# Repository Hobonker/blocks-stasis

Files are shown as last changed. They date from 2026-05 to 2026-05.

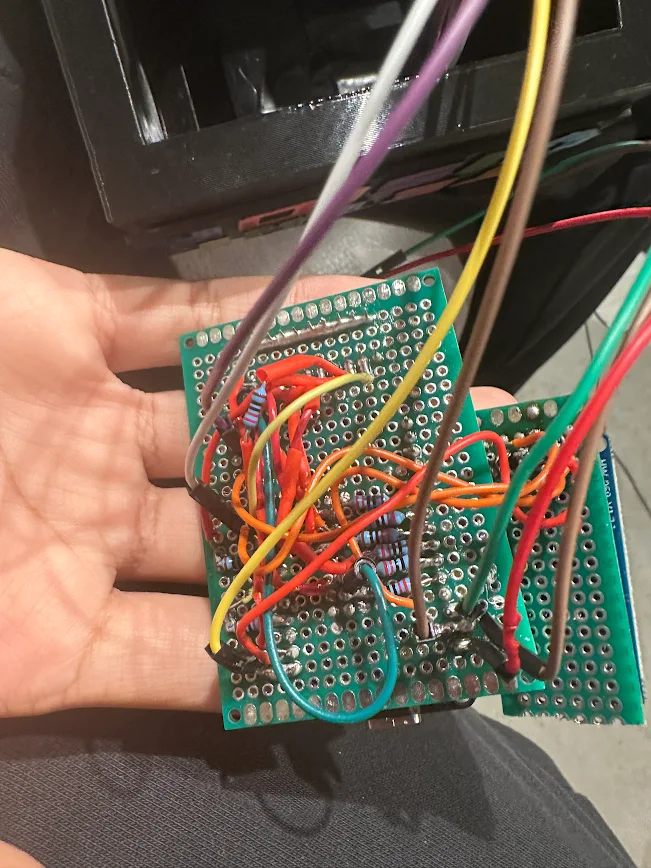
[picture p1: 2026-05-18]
Wiring/Main Perf.webp

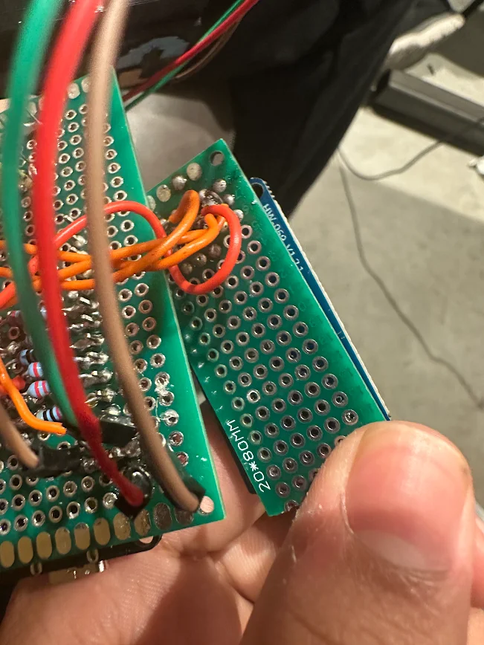
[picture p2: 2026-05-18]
Wiring/OLED.webp

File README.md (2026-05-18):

# TETRIVISION - Gesture Controlled Tetris




Play Tetris with your hands and your voice. A webcam tracks the center of your hand for movement to move and drop pieces, yell into the microphone to rotate pieces clockwise the louder you scream, the more the piece spins. The game itself runs on an ESP32-WROOM driving a 8x32 NeoPixel LED matrix, with a 7-segment display for score, an OLED showing the next piece shape, and a LED bar for mic input volume.

# Demo

https://www.youtube.com/watch?v=66Lr5TsQWm4

# How To Play

- Always keep hand open palm facing the screen
- Place hand at center of the screen (neutral zone)
- Swipe your hand to the left or right to move the falling piece
- Swipe your hand down to hard drop
- Yell to rotate the falling piece clockwise
- Try to clear as many lines as you can by creating rows of 8

# BOM

| Part Name | Count |
|---|---|
| ESP32-S3 | 1 |
| WS2812B NeoPixel Matrix (8x32) | 1 |
| TM1637 4-digit 7-segment display | 1 |
| SSD1306 OLED 0.96" | 1 |
| USB cable (ESP32 to computer) | 1 |
| Webcam (built-in or external) | 1 |
| Microphone (built-in or external) | 1 |
| Computer with USB-C | 1 |
| Perf Board | 1 |
| Jumper Cables | 20 |
| 3D Printed Case | 1 |
| Computer | 1 |
| LED Lights | 1 |

# Wiring Diagram

| From | From Label | To | To Label |
| :--- | :--- | :--- | :--- |
| ESP32 | VIN (5V) | WS2812B Matrix | VCC |
| ESP32 | GND | WS2812B Matrix | GND |
| ESP32 | GPIO13 |  WS2812B Matrix | DIN |
| ESP32 | 3V3 | SSD1306 OLED | VCC |
| ESP32 | GND | SSD1306 OLED | GND |
| ESP32 | GPIO18 | SSD1306 OLED | SCK |
| ESP32 | GPIO23 | SSD1306 OLED | SDA |
| ESP32 | 3V3 | TM1637 7-seg | VCC |
| ESP32 | GND | TM1637 7-seg | GND |
| ESP32 | GPIO22 | TM1637 7-seg | CLK |
| ESP32 | GPIO21 | TM1637 7-seg | DIO |
| ESP32 | GPIO14 | Resistor LED1 | IN |
| Resistor LED1 | OUT | Volume Bar LED1 | DIN |
| ESP32 | GPIO27 | Resistor LED2 | IN |
| Resistor LED2 | OUT | Volume Bar LED2 | DIN |
| ESP32 | GPIO26 | Resistor LED3 | IN |
| Resistor LED3 | OUT | Volume Bar LED3 | DIN |
| ESP32 | GPIO25 | Resistor LED4 | IN |
| Resistor LED4 | OUT | Volume Bar LED4 | DIN |
| ESP32 | GPIO33 | Resistor LED5 | IN |
| Resistor LED5 | OUT | Volume Bar LED5 | DIN |
| ESP32 | GPIO32 | Resistor LED6 | IN |
| Resistor LED6 | OUT | Volume Bar LED6 | DIN |
| ESP32 | GPIO5 | Resistor LED7 | IN |
| Resistor LED7 | OUT | Volume Bar LED7 | DIN |
| ESP32 | GPIO19 | Resistor LED8 | IN |
| Resistor LED8 | OUT | Volume Bar LED8 | DIN |
| ESP32 | GPIO2 | Resistor LED9 | IN |
| Resistor LED9 | OUT | Volume Bar LED9 | DIN |

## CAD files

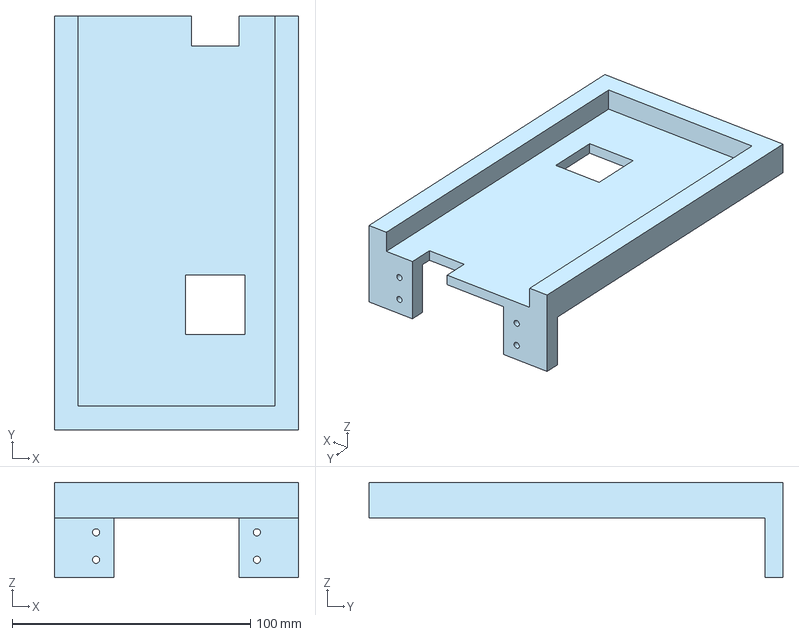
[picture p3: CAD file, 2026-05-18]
CAD/Matrix Display Bottom.step
102.5 x 173.8 x 40.0 mm

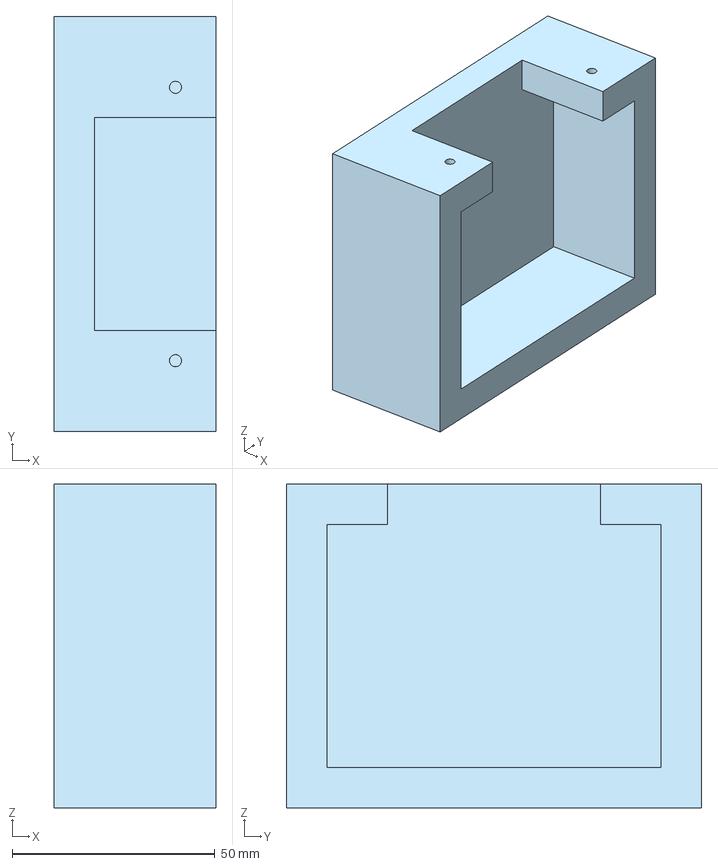
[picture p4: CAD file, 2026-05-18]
CAD/backtop.step
40.0 x 102.5 x 80.0 mm

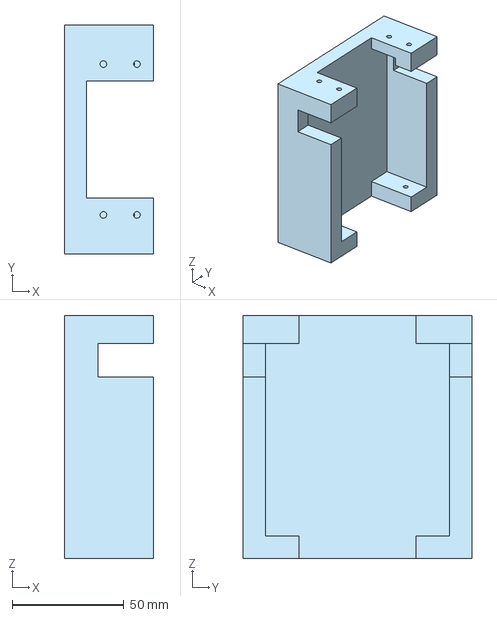
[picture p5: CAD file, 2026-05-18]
CAD/middleback.step
40.0 x 102.5 x 108.8 mm

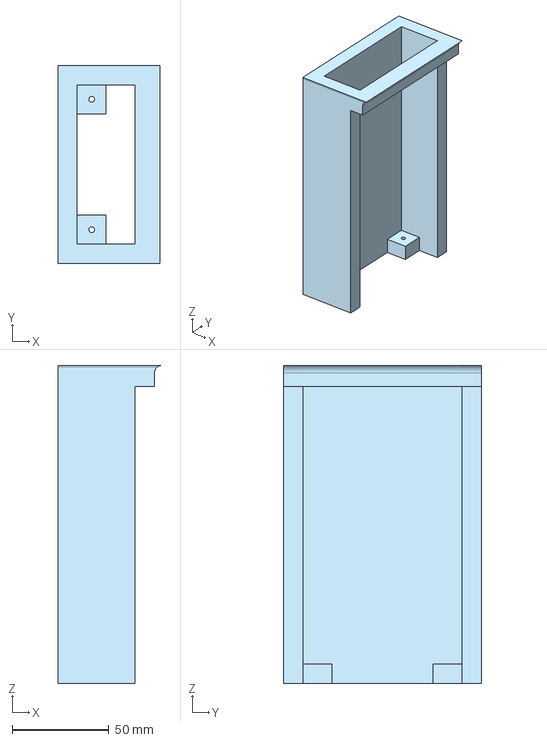
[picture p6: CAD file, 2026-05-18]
CAD/backbottom.step
52.9 x 102.5 x 164.6 mm

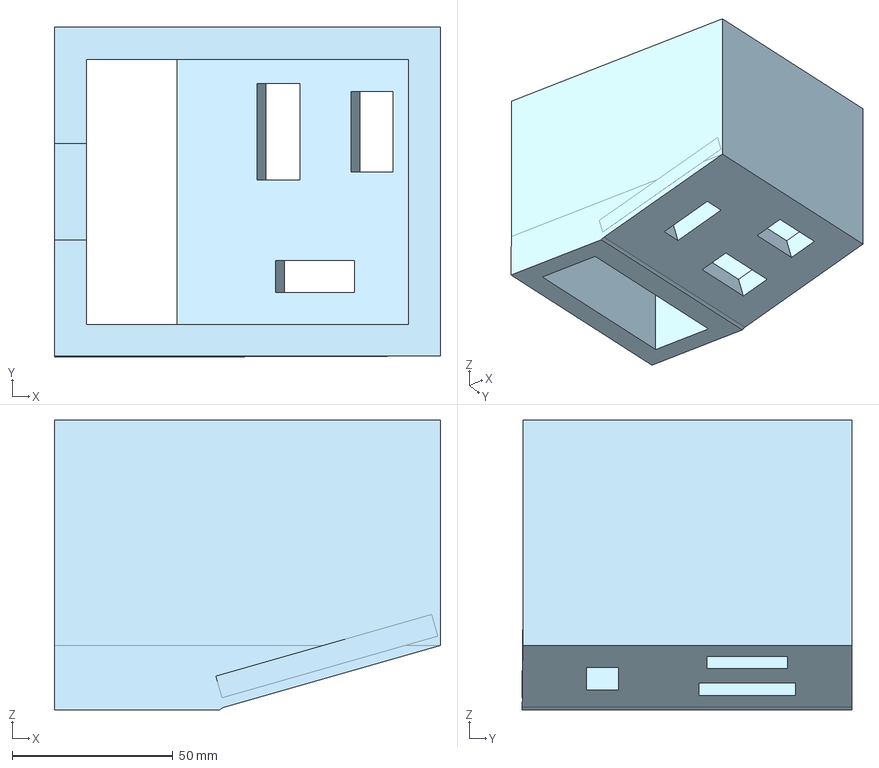
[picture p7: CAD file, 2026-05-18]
CAD/Base Case.step
120.0 x 102.5 x 90.0 mm

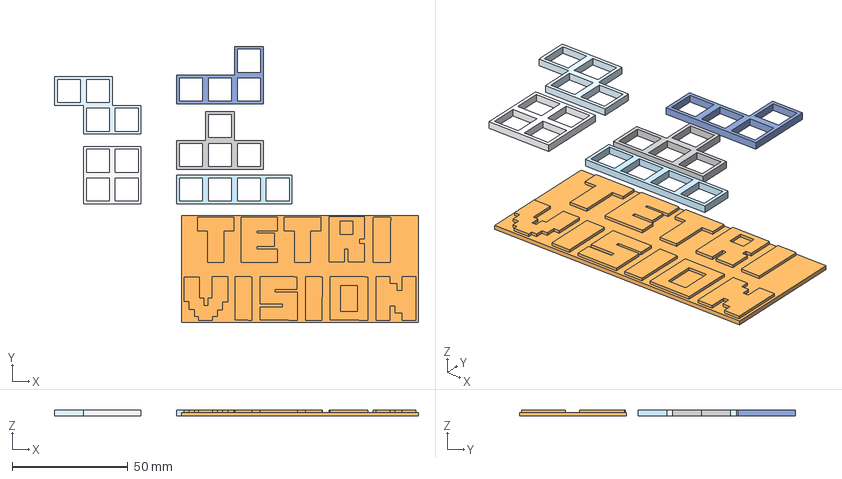
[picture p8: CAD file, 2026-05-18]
CAD/Stencils & Logo.step
157.5 x 119.6 x 2.50 mm

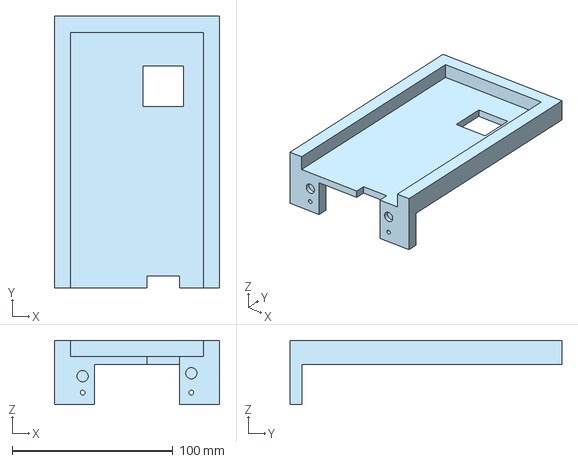
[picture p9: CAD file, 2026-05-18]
CAD/Matrix Display Top.step
102.5 x 168.8 x 40.0 mm

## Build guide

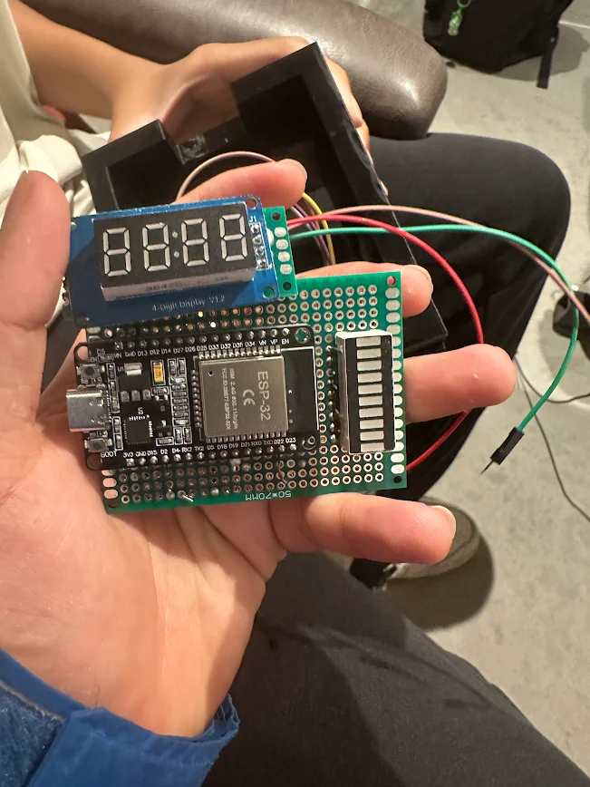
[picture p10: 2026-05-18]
Wiring/Perf Front.webp

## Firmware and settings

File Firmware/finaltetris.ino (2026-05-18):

#include <Adafruit_NeoPixel.h>
#include <TM1637Display.h>
#include <Wire.h>
#include <Adafruit_GFX.h>
#include <Adafruit_SSD1306.h>

// --- NeoPixel ---
#define PIN 13
#define W 8
#define H 32
#define NUM_LEDS (W * H)
Adafruit_NeoPixel strip(NUM_LEDS, PIN, NEO_GRB + NEO_KHZ800);

// --- TM1637 7-seg (score) ---
#define TM_CLK 22
#define TM_DIO 21
TM1637Display display(TM_CLK, TM_DIO);

// --- SSD1306 OLED (next piece) ---
#define OLED_SDA 23
#define OLED_SCL 18
#define SCREEN_WIDTH 128
#define SCREEN_HEIGHT 64
Adafruit_SSD1306 oled(SCREEN_WIDTH, SCREEN_HEIGHT, &Wire, -1);

// --- Volume LED bar ---
const int LED_PINS[]   = {14, 27, 26, 25, 33, 32, 5, 19, 2, 4};
const int NUM_VOL_LEDS = 10;
int currentLevel  = 0;
int targetLevel   = 0;
unsigned long lastDecay = 0;
const int DECAY_INTERVAL = 60;

// --- Start gate ---
bool gameStarted = false;

// --- Game state ---
uint32_t board[H][W];
int curPiece, curRot, curRow, curCol;
uint32_t COLORS[7];
int score = 0;
int incomingPiece = 0;
unsigned long lastFall = 0;
#define FALL_SPEED 600
String serialBuf = "";

const int8_t PIECES[7][4][4][2] = {
  // I
  {{{0,0},{0,1},{0,2},{0,3}},{{0,0},{1,0},{2,0},{3,0}},{{0,0},{0,1},{0,2},{0,3}},{{0,0},{1,0},{2,0},{3,0}}},
  // O
  {{{0,0},{0,1},{1,0},{1,1}},{{0,0},{0,1},{1,0},{1,1}},{{0,0},{0,1},{1,0},{1,1}},{{0,0},{0,1},{1,0},{1,1}}},
  // T
  {{{0,1},{1,0},{1,1},{1,2}},{{0,0},{1,0},{1,1},{2,0}},{{0,0},{0,1},{0,2},{1,1}},{{0,1},{1,0},{1,1},{2,1}}},
  // S
  {{{0,1},{0,2},{1,0},{1,1}},{{0,0},{1,0},{1,1},{2,1}},{{0,1},{0,2},{1,0},{1,1}},{{0,0},{1,0},{1,1},{2,1}}},
  // Z
  {{{0,0},{0,1},{1,1},{1,2}},{{0,1},{1,0},{1,1},{2,0}},{{0,0},{0,1},{1,1},{1,2}},{{0,1},{1,0},{1,1},{2,0}}},
  // J
  {{{0,0},{1,0},{1,1},{1,2}},{{0,0},{0,1},{1,0},{2,0}},{{0,0},{0,1},{0,2},{1,2}},{{0,1},{1,1},{2,0},{2,1}}},
  // L
  {{{0,2},{1,0},{1,1},{1,2}},{{0,0},{1,0},{2,0},{2,1}},{{0,0},{0,1},{0,2},{1,0}},{{0,0},{0,1},{1,1},{2,1}}}
};

const bool PIECE_PREVIEW[7][4][4] = {
  {{0,0,0,0},{1,1,1,1},{0,0,0,0},{0,0,0,0}},  // I
  {{0,1,1,0},{0,1,1,0},{0,0,0,0},{0,0,0,0}},  // O
  {{0,1,0,0},{1,1,1,0},{0,0,0,0},{0,0,0,0}},  // T
  {{0,1,1,0},{1,1,0,0},{0,0,0,0},{0,0,0,0}},  // S
  {{1,1,0,0},{0,1,1,0},{0,0,0,0},{0,0,0,0}},  // Z
  {{1,0,0,0},{1,1,1,0},{0,0,0,0},{0,0,0,0}},  // J
  {{0,0,1,0},{1,1,1,0},{0,0,0,0},{0,0,0,0}}   // L
};

const char* PIECE_NAMES[7] = {"I","O","T","S","Z","J","L"};

// ─── Helpers ─────────────────────────────────────────────

void updateVolumeLEDs() {
  if (millis() - lastDecay > DECAY_INTERVAL) {
    if (currentLevel > 0) currentLevel--;
    lastDecay = millis();
  }
  for (int i = 0; i < NUM_VOL_LEDS; i++)
    digitalWrite(LED_PINS[i], i < currentLevel ? HIGH : LOW);
}

void drawNextPiece(int piece) {
  oled.clearDisplay();
  oled.setTextSize(1);
  oled.setTextColor(SSD1306_WHITE);
  oled.setCursor(0, 0);
  oled.print("NEXT:");
  oled.print(PIECE_NAMES[piece]);

  int cellSize = 14, gap = 2;
  int gridW = 4 * (cellSize + gap);
  int gridH = 4 * (cellSize + gap);
  int startX = (SCREEN_WIDTH - gridW) / 2;
  int startY = (SCREEN_HEIGHT - gridH) / 2 + 8;

  for (int r = 0; r < 4; r++)
    for (int c = 0; c < 4; c++)
      if (PIECE_PREVIEW[piece][r][c])
        oled.fillRect(startX + c*(cellSize+gap), startY + r*(cellSize+gap), cellSize, cellSize, SSD1306_WHITE);
  oled.display();
}

int xyToLED(int row, int col) {
  int flippedRow = (H - 1) - row;
  if (flippedRow % 2 == 0) return flippedRow * W + col;
  else return flippedRow * W + (W - 1 - col);
}

bool collides(int piece, int rot, int row, int col) {
  for (int i = 0; i < 4; i++) {
    int r = row + PIECES[piece][rot][i][0];
    int c = col + PIECES[piece][rot][i][1];
    if (r < 0 || r >= H || c < 0 || c >= W) return true;
    if (board[r][c]) return true;
  }
  return false;
}

void lockPiece() {
  for (int i = 0; i < 4; i++) {
    int r = curRow + PIECES[curPiece][curRot][i][0];
    int c = curCol + PIECES[curPiece][curRot][i][1];
    if (r >= 0 && r < H && c >= 0 && c < W)
      board[r][c] = COLORS[curPiece];
  }
  score += 10;
  display.showNumberDec(score, false);
  Serial.print("Score: "); Serial.println(score);
}

void clearLines() {
  for (int r = H - 1; r >= 0; r--) {
    bool full = true;
    for (int c = 0; c < W; c++)
      if (!board[r][c]) { full = false; break; }
    if (full) {
      for (int rr = r; rr > 0; rr--)
        for (int c = 0; c < W; c++)
          board[rr][c] = board[rr-1][c];
      for (int c = 0; c < W; c++)
        board[0][c] = 0;
      r++;
      score += 50;
      display.showNumberDec(score, false);
      Serial.print("Score: "); Serial.println(score);
    }
  }
}

void render() {
  for (int r = 0; r < H; r++)
    for (int c = 0; c < W; c++)
      strip.setPixelColor(xyToLED(r, c), board[r][c]);
  for (int i = 0; i < 4; i++) {
    int r = curRow + PIECES[curPiece][curRot][i][0];
    int c = curCol + PIECES[curPiece][curRot][i][1];
    if (r >= 0 && r < H && c >= 0 && c < W)
      strip.setPixelColor(xyToLED(r, c), COLORS[curPiece]);
  }
  strip.show();
}

void showIdleScreen() {
  // Blue border on NeoPixel matrix, everything else black
  strip.clear();
  for (int c = 0; c < W; c++) {
    strip.setPixelColor(xyToLED(0, c),   strip.Color(0, 0, 60));
    strip.setPixelColor(xyToLED(H-1, c), strip.Color(0, 0, 60));
  }
  for (int r = 1; r < H-1; r++) {
    strip.setPixelColor(xyToLED(r, 0),   strip.Color(0, 0, 60));
    strip.setPixelColor(xyToLED(r, W-1), strip.Color(0, 0, 60));
  }
  strip.show();

  // OLED waiting message
  oled.clearDisplay();
  oled.setTextSize(1);
  oled.setTextColor(SSD1306_WHITE);
  oled.setCursor(0, 20);
  oled.print("  TETRIS");
  oled.setCursor(0, 36);
  oled.print("Press SPACE");
  oled.setCursor(0, 48);
  oled.print("  to start");
  oled.display();

  display.showNumberDec(0, false);
  Serial.println("Waiting for start — press SPACE in the Python controller.");
}

void spawnPiece() {
  curPiece = incomingPiece;
  incomingPiece = random(7);
  curRot = 0; curRow = 0;
  curCol = W / 2 - 1;
  drawNextPiece(incomingPiece);
  Serial.print("Incoming: "); Serial.println(incomingPiece);
  if (collides(curPiece, curRot, curRow, curCol)) {
    memset(board, 0, sizeof(board));
    score = 0;
    display.showNumberDec(0, false);
    oled.clearDisplay();
    oled.setTextSize(2);
    oled.setTextColor(SSD1306_WHITE);
    oled.setCursor(10, 20);
    oled.print("GAME OVER");
    oled.display();
    Serial.println("Game over! Score reset.");
    delay(2000);
    // Return to idle — wait for another 'S' to restart
    gameStarted = false;
    showIdleScreen();
  }
}

// ─── Setup ───────────────────────────────────────────────

void setup() {
  for (int i = 0; i < NUM_VOL_LEDS; i++) {
    pinMode(LED_PINS[i], OUTPUT);
    digitalWrite(LED_PINS[i], LOW);
  }

  Serial.begin(115200);
  Wire.begin(OLED_SDA, OLED_SCL);

  display.setBrightness(7);
  display.showNumberDec(0, false);

  if (!oled.begin(SSD1306_SWITCHCAPVCC, 0x3C)) {
    Serial.println("OLED init failed");
    while (true);
  }
  oled.setRotation(2);
  oled.clearDisplay();
  oled.display();

  strip.begin();
  strip.setBrightness(40);
  strip.clear();
  strip.show();

  COLORS[0] = strip.Color(0,   200, 200);  // I - cyan
  COLORS[1] = strip.Color(200, 200, 0);    // O - yellow
  COLORS[2] = strip.Color(150, 0,   150);  // T - purple
  COLORS[3] = strip.Color(0,   200, 0);    // S - green
  COLORS[4] = strip.Color(200, 0,   0);    // Z - red
  COLORS[5] = strip.Color(0,   0,   200);  // J - blue
  COLORS[6] = strip.Color(200, 100, 0);    // L - orange

  randomSeed(analogRead(0));
  memset(board, 0, sizeof(board));
  score = 0;
  gameStarted = false;
  incomingPiece = random(7);

  // Force a full clear render so any leftover board from a previous run is wiped
  strip.clear();
  strip.show();
  delay(50);

  showIdleScreen();
}

// ─── Loop ────────────────────────────────────────────────

void loop() {
  while (Serial.available()) {
    char c = Serial.read();

    // Start command
    if (c == 'S' && !gameStarted) {
      gameStarted = true;
      memset(board, 0, sizeof(board));
      score = 0;
      display.showNumberDec(0, false);
      incomingPiece = random(7);
      spawnPiece();
      lastFall = millis();
      Serial.println("Game started!");
      return;
    }

    if (c == '\n') {
      serialBuf.trim();
      if (serialBuf.length() > 0) {
        bool isNumber = true;
        for (int i = 0; i < (int)serialBuf.length(); i++)
          if (!isDigit(serialBuf[i])) { isNumber = false; break; }
        if (isNumber) {
          int val = serialBuf.toInt();
          if (val >= 0 && val <= 10) {
            if (val > currentLevel) currentLevel = val;
            targetLevel = val;
          }
        }
      }
      serialBuf = "";
    } else if (gameStarted && (c == 'L' || c == 'R' || c == 'U' || c == 'D')) {
      serialBuf = "";
      if (c == 'L' && !collides(curPiece, curRot, curRow, curCol - 1)) curCol--;
      if (c == 'R' && !collides(curPiece, curRot, curRow, curCol + 1)) curCol++;
      if (c == 'U') {
        int nr = (curRot + 1) % 4;
        if (!collides(curPiece, nr, curRow, curCol)) curRot = nr;
      }
      if (c == 'D') {
        while (!collides(curPiece, curRot, curRow + 1, curCol)) curRow++;
        lockPiece(); clearLines(); spawnPiece();
        lastFall = millis();
      }
    } else {
      serialBuf += c;
    }
  }

  // Only tick and render when game is live
  if (!gameStarted) {
    updateVolumeLEDs();
    return;  // <-- exits before render(), idle screen stays intact
  }

  if (millis() - lastFall >= FALL_SPEED) {
    lastFall = millis();
    if (!collides(curPiece, curRot, curRow + 1, curCol)) {
      curRow++;
    } else {
      lockPiece(); clearLines(); spawnPiece();
    }
  }

  render();
  updateVolumeLEDs();
}

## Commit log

2026-05-18 Create CAD folder
2026-05-18 Create Wiring Folder
2026-05-18 Rename project and enhance README content
    Updated project name and description, added wiring diagram.
